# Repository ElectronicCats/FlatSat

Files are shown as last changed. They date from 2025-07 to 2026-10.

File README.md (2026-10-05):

# Flatsat 

<p align="center">
    <a href="https://github.com/ElectronicCats/FlatSat/wiki">
        
    </a>
</p>

<p align=center>
    <a href="https://electroniccats.com/store/flatsat1/">
        
    </a>
    <a href="https://github.com/ElectronicCats/FlatSat/wiki">
        
    </a>
</p>

Flatsat is a hardware based training platform designed to be vulnerable on purpose. It’s built for hackers, engineers, and space enthusiasts who want to dive deep into space-grade systems, learn cybersecurity concepts, and prototype their own payloads.

Flatsat is designed to help you learn and prototype radio systems safely and legally, all while gaining real-world skills in RF communication, signal analysis, and protocol fuzzing.

## What You Can Do With Flatsat
- **Hands-on Learning:** Use Flatsat as the hardware companion to the [**PwnSat**](https://pwnsat.org/) course, with structured lessons on binary exploitation, secure communication, reverse engineering, and space protocols.
- **Hack Real Vulnerabilities:**  Explore and exploit firmware designed to simulate real-world satellite systems and vulnerabilities. It’s a safe playground for learning and discovery.
- **Join the Mission CTF:**  Participate in space-themed capture-the-flag challenges that simulate real satellite operation scenarios.
- **Prototype Your Payloads:**  Use the onboard components to develop and test your own payload logic, radio communication, or telemetry systems before launching bigger projects.

> [!IMPORTANT]
> **This project was created for educational purposes, to teach and learn aerospace cybersecurity. Neither PWNSAT nor Electronic Cats are responsible for how the knowledge, code, or tools hosted in the official repository are used. Use only against hardware, firmware, or signal sources you own or are explicitly authorized to test.**
> 
> Flatsat uses ISM (Industrial, Scientific, and Medical) band frequencies for all RF communication,  typically 433 MHz or 915 MHz, depending on your region. These frequencies are internationally reserved for unlicensed, experimental, and educational use.
>
> This ensures that Flatsat does not interfere with any production space systems, licensed satellites, or critical ground infrastructure.

## Hardware Infrastructure

The infrastructure is designed for **FlatSat** testing, where hardware components are laid out for accessibility and auditing.

| **Component** | **Description** | **Interface** |
| --- | --- | --- |
| **MCU** | Raspberry Pi RP2040 | Dual Core ARM Cortex-M0+ |
| **Radio 0** | SX1262 LoRa (Uplink) | SPI0 / NSS Pin 17 |
| **Radio 1** | SX1262 LoRa (Downlink) | SPI0 / NSS Pin 5 |
| **IMU** | LIS2DH12 Accelerometer | I2C (SDA 20, SCL 21) |
| **ENV** | BME280 Environment Sensor | I2C (SDA 20, SCL 21) |
| **Status** | WS2812B NeoPixel | GPIO 15 |

##  FlatSat Firmware

The firmware splits tasks across two cores, the system ensures that high-speed data links do not interfere with time-critical radio operations.

The firmware is located in a different repository: https://github.com/ElectronicCats/flatsat-ground-station

The core of the communication system is the [**CCSDS Space Packet Protocol**](https://ccsds.org/Pubs/133x0b2e2.pdf). This allows the spacecraft to route data using **Application Process Identifiers (APIDs)**, enabling modular subsystem addressing.

Modern satellites are no longer isolated systems; they are software-defined assets. The vulnerabilities identified in this firmware mirror historical "anomalies" and documented attacks on orbiting infrastructure.

Since the firmware lacks a Cryptographic Authentication layer, the system is vulnerable to **Command Spoofing**.

An attacker uses a Software Defined Radio (SDR) to capture a legitimate "Telemetry" packet to identify the `SPACECRAFT_ID` and the current `Sequence Count`.
  
This happened in the real world. In 1998, the **ROSAT** (Röntgen Satellite) was allegedly compromised via a ground station breach, where attackers sent commands to point the solar panels directly at the sun, eventually frying the batteries. While that was a network breach, the lack of authentication on the RF link makes this firmware susceptible to the same outcome.

## Technical Documentation and Guides (Wiki)

All deep technical documentation, source analysis, and setup guides have been centralized. If you want to start debugging, or exploiting the platform, please visit the [FlatSat Wiki](https://github.com/ElectronicCats/FlatSat/wiki). The information from the Pwnsat repository has been included in our wiki.

## How to contribute 

[pwnsat.org](https://pwnsat.org/) and [flatsat.org](https://flatsat.org/)
Contributions are welcome!

Please read the document [**Contribution manual**](https://github.com/ElectronicCats/electroniccats-cla/blob/main/electroniccats-contribution-manual.md) which will show you how to contribute your changes to the project.

✨ Thanks to all our [Contributors](https://github.com/ElectronicCats/Flatsat/graphs/contributors)! ✨

See [**_Electronic Cats CLA_**](https://github.com/ElectronicCats/electroniccats-cla/blob/main/electroniccats-cla.md) for more information.

See the [**Community code of conduct**](https://github.com/ElectronicCats/electroniccats-cla/blob/main/electroniccats-community-code-of-conduct.md) for a vision of the community we want to build and what we expect from it.

## License

Electronic Cats invests time and resources providing this open source design, please support Electronic Cats and open-source hardware by purchasing products from Electronic Cats!

Designed by Electronic Cats and PWNSAT.

Hardware released under an CERN Open Hardware Licence v1.2. See the LICENSE_HARDWARE file for more information.

Electronic Cats and PWNSAT is a registered trademark, please do not use if you sell these PCBs.

## Special Thanks
A special thanks to **Alex Lynd**. His support made it possible to kick off the first version of the project, and his contribution remains a fundamental part of PwnSat. His work will always be embedded in what this project has become.

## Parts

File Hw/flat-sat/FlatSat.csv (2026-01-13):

Reference | Value | Footprint | Qty | LCSC# | Mouser# | manf# | DNP
BOOT1,Button1,Button2,RESET1 | SW | FlatSat:TS1088R02026 | 4 | C455281
C1,C5,C7,C8,C13,C14,C18,C19,C24,C25,C27,C28,C32,C33,C34,C35,C36,C37,C38 | 0.1uF | Capacitor_SMD:C_0402_1005Metric | 19 | C56392
C2,C15 | 100pF | Capacitor_SMD:C_0402_1005Metric | 2 | C541374
C3,C4,C16,C17 | 3.3pF | Capacitor_SMD:C_0402_1005Metric | 4 | C1565
C6,C26,C31 | 1uF | Capacitor_SMD:C_0402_1005Metric | 3 | C52923
C9,C20 | 47pF | Capacitor_SMD:C_0402_1005Metric | 2 | C437519
C10,C12,C21,C23 | 1nF | Capacitor_SMD:C_0402_1005Metric | 4 | C335530
C11,C22 | 470nF | Capacitor_SMD:C_0402_1005Metric | 2 | C47339
C29,C30 | 27pF | Capacitor_SMD:C_0402_1005Metric | 2 | C424826 | 81-GJM1555C1H270FB1D
D2 | SK6812MINI | Library:SK6812MINI-HS | 1 | C2922787
F1 | 0.75A | Fuse:Fuse_0603_1608Metric_Pad1.05x0.95mm_HandSolder | 1 | C182438 | 594-MFU0805FF00500P1
J1,J2 | Antenna | FlatSat:SMA_EDGE | 2 | C530661
J3 | periphs | Connector_PinHeader_2.54mm:PinHeader_1x06_P2.54mm_Vertical | 1
J4 | SWD | Connector_PinHeader_2.54mm:PinHeader_1x04_P2.54mm_Vertical | 1 |  |  |  | DNP
JP1,JP2 | Jumper | Jumper:SolderJumper-3_P1.3mm_Bridged12_RoundedPad1.0x1.5mm_NumberLabels | 2 |  |  |  | DNP
L1,L4 | 9.1nH | Inductor_SMD:L_0603_1608Metric | 2 | C395094
L2,L5 | 47nH | Inductor_SMD:L_0603_1608Metric | 2 | C578001
L3,L6 | 15uH | Inductor_SMD:L_0603_1608Metric | 2 | C57838
P1 | USB_C_Plug_USB2.0 | FlatSat:C393939 | 1 | C709357
R1,R2 | 5k1 | Resistor_SMD:R_0402_1005Metric | 2 | C25905
R3,R4,R6,R7 | 100R | Resistor_SMD:R_0402_1005Metric | 4 | C25076
R5 | 10k | Resistor_SMD:R_0402_1005Metric | 1 | C25531 | 594-MCS04020D1002BE0
R8,R10 | 27 | Resistor_SMD:R_0402_1005Metric | 2 | C25100 | 755-ESR01MZPF27R0
R9,R15 | 4.7k | Resistor_SMD:R_0402_1005Metric | 2 | C25900 | 594-MCS04020D1002BE0
R13 | 1k | Resistor_SMD:R_0402_1005Metric | 1 | C11702 | 594-MCS0402MD1001DE0
R14 | 470 | Resistor_SMD:R_0402_1005Metric | 1 | C25117
U1 | TLV75733PDBVR | Package_TO_SOT_SMD:SOT-23-5 | 1 | C485517
U2,U6 | 0900FM15D0039 | FlatSat:0900FM15D0039E | 2 |  | 609-0900FM15D0039E | 0900FM15D0039E
U3,U7 | PE42421 | Package_TO_SOT_SMD:SOT-363_SC-70-6 | 2 | C470893 | 81-PE42421SCAA-Z | PE42421SCAA-Z
U4,U8 | SX1262IMLTRT | Package_DFN_QFN:QFN-24-1EP_4x4mm_P0.5mm_EP2.65x2.65mm | 2 | C191341 | 947-SX1262IMLTRT | SX1262IMLTRT
U5 | W25Q16JV | Package_SON:Winbond_USON-8-2EP_3x4mm_P0.8mm_EP0.2x0.8mm | 1 | C571259 | 454-W25Q16JVUUIQTR | W25Q16JVUUIQ TR
U9 | RP2040 | Package_DFN_QFN:QFN-56-1EP_7x7mm_P0.4mm_EP3.2x3.2mm | 1 | C2040 |  | RP2040
U10 | LIS2DH | Package_LGA:LGA-14_2x2mm_P0.35mm_LayoutBorder3x4y | 1 | C155670
U11 | BME280 /BMP280 | Package_LGA:Bosch_LGA-8_2.5x2.5mm_P0.65mm_ClockwisePinNumbering | 1 | C92489
Y1,Y2 | 32Mhz | Crystal:Crystal_SMD_2520-4Pin_2.5x2.0mm | 2 | C255969 |  | Q24FA20H0021700
Y3 | 12MHz | Crystal:Crystal_SMD_3225-4Pin_3.2x2.5mm | 1 | C2848217 |  | XC32M4-12.000-F20NJDT

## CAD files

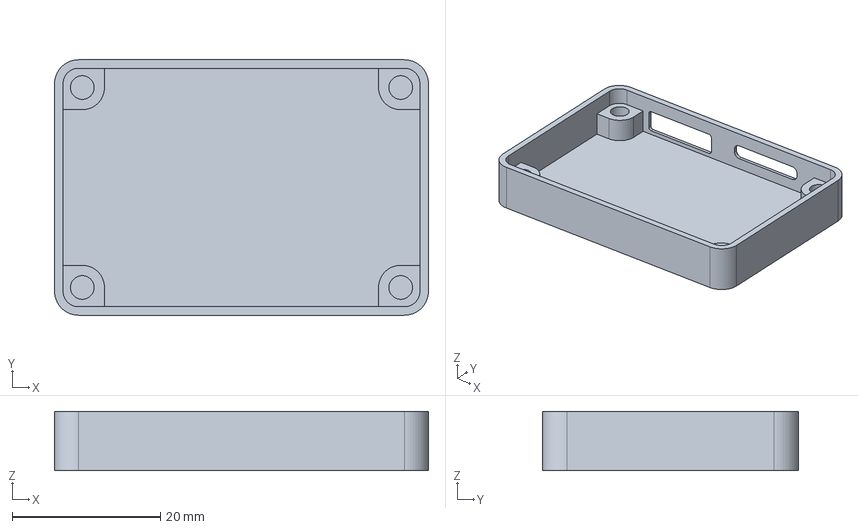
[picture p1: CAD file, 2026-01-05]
Hw/v0.2/v0-FlatSat-Enclosure.FCStd
50.5 x 34.5 x 8.00 mm

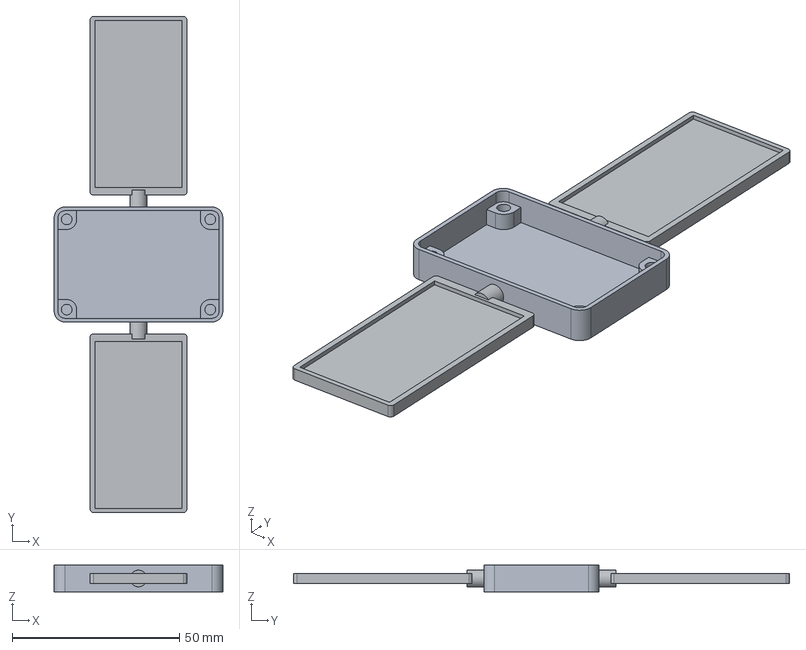
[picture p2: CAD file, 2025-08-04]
Hw/v0.2/v0-FlatSat-Sat-SolarPanel.step
50.5 x 148.5 x 8.00 mm
SolarPanel2
SolarPanel1

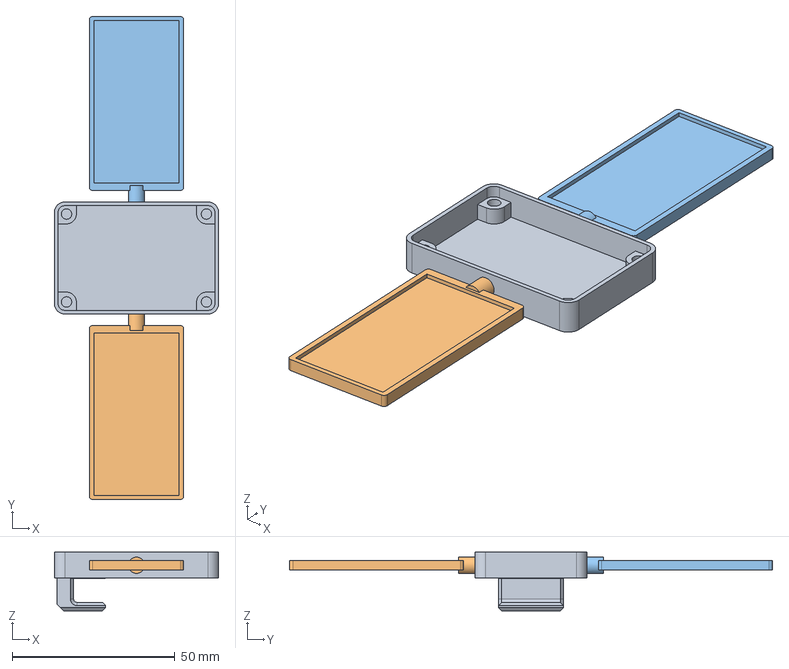
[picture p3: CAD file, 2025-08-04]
Hw/v0.2/v0-FlatSat-Sat_MOunt.FCStd
50.5 x 148.5 x 18.0 mm
SolarPanel2
SolarPanel1

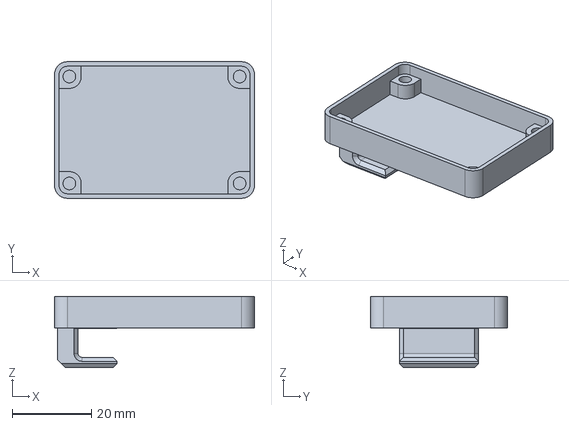
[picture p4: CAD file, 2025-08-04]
Hw/v0.2/v0-FlatSat-Mount.FCStd
50.5 x 34.5 x 18.0 mm

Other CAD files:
Hw/v0.2/v0-FlatSat-Enclosure-Body_STL.stl
Hw/v0.2/v0-FlatSat-Sat.FCStd
Hw/v0.2/v0-FlatSat-Outline.FCStd
Hw/v0.2/v0-FlatSat-Sat-Mount.stl
Hw/v0.2/v0-FlatSat-Sat-SolarPanel.stl

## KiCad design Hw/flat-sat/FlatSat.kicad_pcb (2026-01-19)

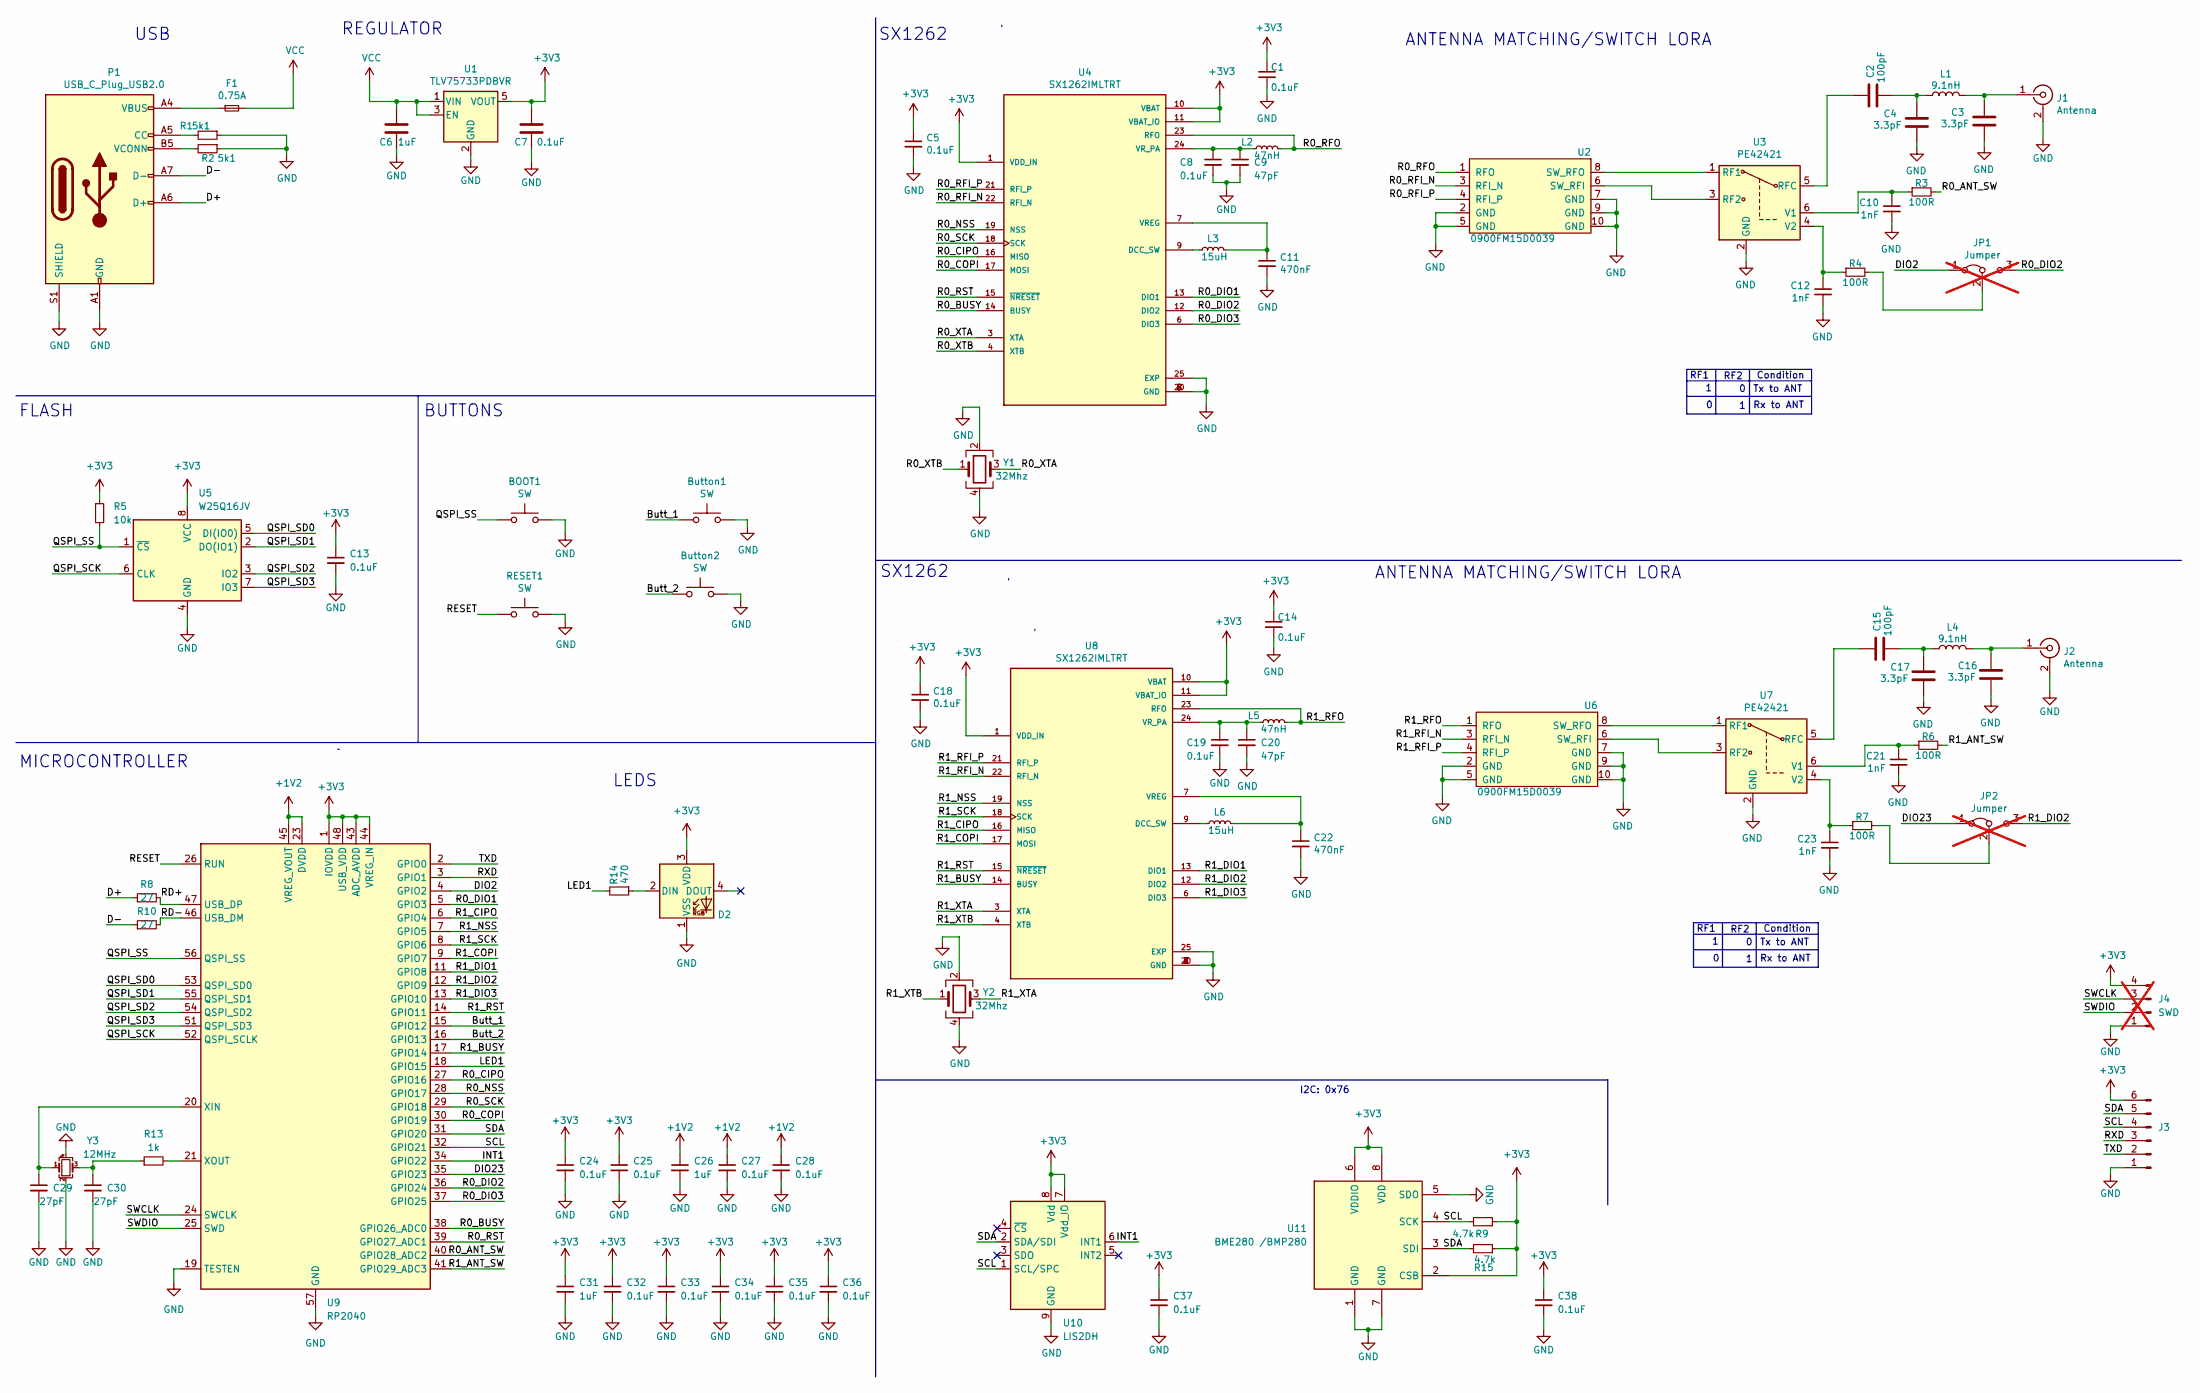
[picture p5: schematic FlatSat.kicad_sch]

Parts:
BOOT1: SW; TS1088R02026; LCSC# C455281
Button1, Button2: SW; TS1088R02026; LCSC# C455281
C1, C5, C7, C8, C13, C14, C18, C19, C24, C25, C27, C28, C32, C33, C34, C35, C36, C37, C38: 0.1uF; C_0402_1005Metric; LCSC# C56392
C2, C15: 100pF; C_0402_1005Metric; LCSC# C541374
C3, C4, C16, C17: 3.3pF; C_0402_1005Metric; LCSC# C1565
C6, C26, C31: 1uF; C_0402_1005Metric; LCSC# C52923
C9, C20: 47pF; C_0402_1005Metric; LCSC# C437519
C10, C12, C21, C23: 1nF; C_0402_1005Metric; LCSC# C335530
C11, C22: 470nF; C_0402_1005Metric; LCSC# C47339
C29, C30: 27pF; C_0402_1005Metric; Mouser# 81-GJM1555C1H270FB1D; LCSC# C424826
D2: SK6812MINI; SK6812MINI-HS; LCSC# C2922787
F1: 0.75A; Fuse_0603_1608Metric_Pad1.05x0.95mm_HandSolder; Mouser# 594-MFU0805FF00500P1
J1, J2: Antenna; SMA_EDGE; LCSC# C530661
J3: periphs; PinHeader_1x06_P2.54mm_Vertical
J4: SWD; PinHeader_1x04_P2.54mm_Vertical; not fitted
JP1, JP2: Jumper; SolderJumper-3_P1.3mm_Bridged12_RoundedPad1.0x1.5mm_NumberL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; not fitted
L1, L4: 9.1nH; L_0603_1608Metric; LCSC# C395094
L2, L5: 47nH; L_0603_1608Metric; LCSC# C578001
L3, L6: 15uH; L_0603_1608Metric; LCSC# C57838
P1: USB_C_Plug_USB2.0; C393939; LCSC# C709357
R1, R2: 5k1; R_0402_1005Metric; LCSC# C25905
R3, R4, R6, R7: 100R; R_0402_1005Metric; LCSC# C25076
R5: 10k; R_0402_1005Metric; Mouser# 594-MCS04020D1002BE0; LCSC# C25531
R8, R10: 27; R_0402_1005Metric; Mouser# 755-ESR01MZPF27R0; LCSC# C25100
R9, R15: 4.7k; R_0402_1005Metric; Mouser# 594-MCS04020D1002BE0; LCSC# C25900
R13: 1k; R_0402_1005Metric; Mouser# 594-MCS0402MD1001DE0; LCSC# C11702
R14: 470; R_0402_1005Metric; LCSC# C25117
RESET1: SW; TS1088R02026; LCSC# C455281
U1: TLV75733PDBVR; SOT-23-5; LCSC# C485517
U2, U6: 0900FM15D0039; 0900FM15D0039E; Mouser# 609-0900FM15D0039E
U3, U7: PE42421; SOT-363_SC-70-6; Mouser# 81-PE42421SCAA-Z; LCSC# C470893
U4, U8: SX1262IMLTRT; QFN-24-1EP_4x4mm_P0.5mm_EP2.65x2.65mm; Mouser# 947-SX1262IMLTRT
U5: W25Q16JV; Winbond_USON-8-2EP_3x4mm_P0.8mm_EP0.2x0.8mm; Mouser# 454-W25Q16JVUUIQTR
U9: RP2040; QFN-56-1EP_7x7mm_P0.4mm_EP3.2x3.2mm; LCSC# C2040
U10: LIS2DH; LGA-14_2x2mm_P0.35mm_LayoutBorder3x4y; LCSC# C155670
U11: BME280 /BMP280; Bosch_LGA-8_2.5x2.5mm_P0.65mm_ClockwisePinNumbering; LCSC# C92489
Y1, Y2: 32Mhz; Crystal_SMD_2520-4Pin_2.5x2.0mm; LCSC# C255969
Y3: 12MHz; Crystal_SMD_3225-4Pin_3.2x2.5mm; LCSC# C2848217

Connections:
+1V2: C26.1, C27.1, C28.1, U9.23 (DVDD), U9.45 (VREG_VOUT), U9.50 (DVDD)
+3V3: C1.1, C5.1, C7.2, C13.1, C14.1, C18.1, C24.1, C25.1, C31.1, C32.1, C33.1, C34.1, C35.1, C36.1, C37.1, C38.1, D2.3 (VDD), J3.6, J4.4, R5.1, R9.1, R15.1, U1.5 (VOUT), U4.1 (VDD_IN), U4.10 (VBAT), U4.11 (VBAT_IO), U5.8 (VCC), U8.1 (VDD_IN), U8.10 (VBAT), U8.11 (VBAT_IO), U9.1 (IOVDD), U9.10 (IOVDD), U9.22 (IOVDD), U9.33 (IOVDD), U9.42 (IOVDD), U9.43 (ADC_AVDD), U9.44 (VREG_IN), U9.48 (USB_VDD), U9.49 (IOVDD), U10.7 (Vdd_IO), U10.8 (Vdd), U11.2 (CSB), U11.6 (VDDIO), U11.8 (VDD)
/Butt_1: Button1.1, U9.15 (GPIO12)
/Butt_2: Button2.1, U9.16 (GPIO13)
/D+: P1.A6 (D+), R8.1
/D-: P1.A7 (D-), R10.1
/DIO2: JP1.1 (A), U9.4 (GPIO2)
/DIO23: JP2.1 (A), U9.35 (GPIO23)
/INT1: U9.34 (GPIO22), U10.6 (INT1)
/LED1: R14.2, U9.18 (GPIO15)
/QSPI_SCK: U5.6 (CLK), U9.52 (QSPI_SCLK)
/QSPI_SD0: U5.5 (DI(IO0)), U9.53 (QSPI_SD0)
/QSPI_SD1: U5.2 (DO(IO1)), U9.55 (QSPI_SD1)
/QSPI_SD2: U5.3 (IO2), U9.54 (QSPI_SD2)
/QSPI_SD3: U5.7 (IO3), U9.51 (QSPI_SD3)
/QSPI_SS: BOOT1.1, R5.2, U5.1 (~CS), U9.56 (QSPI_SS)
/R0_ANT_SW: R3.2, U9.40 (GPIO28_ADC2)
/R0_BUSY: U4.14 (BUSY), U9.38 (GPIO26_ADC0)
/R0_CIPO: U4.16 (MISO), U9.27 (GPIO16)
/R0_COPI: U4.17 (MOSI), U9.30 (GPIO19)
/R0_DIO1: U4.13 (DIO1), U9.5 (GPIO3)
/R0_DIO2: JP1.3 (B), U4.12 (DIO2), U9.36 (GPIO24)
/R0_DIO3: U4.6 (DIO3), U9.37 (GPIO25)
/R0_NSS: U4.19 (NSS), U9.28 (GPIO17)
/R0_RFI_N: U2.3 (RFI_N), U4.22 (RFI_N)
/R0_RFI_P: U2.4 (RFI_P), U4.21 (RFI_P)
/R0_RFO: L2.2, U2.1 (RFO), U4.23 (RFO)
/R0_RST: U4.15 (~NRESET), U9.39 (GPIO27_ADC1)
/R0_SCK: U4.18 (SCK), U9.29 (GPIO18)
/R0_XTA: U4.3 (XTA), Y1.3
/R0_XTB: U4.4 (XTB), Y1.1
/R1_ANT_SW: R6.2, U9.41 (GPIO29_ADC3)
/R1_BUSY: U8.14 (BUSY), U9.17 (GPIO14)
/R1_CIPO: U8.16 (MISO), U9.6 (GPIO4)
/R1_COPI: U8.17 (MOSI), U9.9 (GPIO7)
/R1_DIO1: U8.13 (DIO1), U9.11 (GPIO8)
/R1_DIO2: JP2.3 (B), U8.12 (DIO2), U9.12 (GPIO9)
/R1_DIO3: U8.6 (DIO3), U9.13 (GPIO10)
/R1_NSS: U8.19 (NSS), U9.7 (GPIO5)
/R1_RFI_N: U6.3 (RFI_N), U8.22 (RFI_N)
/R1_RFI_P: U6.4 (RFI_P), U8.21 (RFI_P)
/R1_RFO: L5.2, U6.1 (RFO), U8.23 (RFO)
/R1_RST: U8.15 (~NRESET), U9.14 (GPIO11)
/R1_SCK: U8.18 (SCK), U9.8 (GPIO6)
/R1_XTA: U8.3 (XTA), Y2.3
/R1_XTB: U8.4 (XTB), Y2.1
/RD+: R8.2, U9.47 (USB_DP)
/RD-: R10.2, U9.46 (USB_DM)
/RESET: RESET1.1, U9.26 (RUN)
/RXD: J3.3, U9.3 (GPIO1)
/SCL: J3.4, R9.2, U9.32 (GPIO21), U10.1 (SCL/SPC), U11.4 (SCK)
/SDA: J3.5, R15.2, U9.31 (GPIO20), U10.2 (SDA/SDI), U11.3 (SDI)
/SWCLK: J4.3, U9.24 (SWCLK)
/SWDIO: J4.2, U9.25 (SWD)
/TXD: J3.2, U9.2 (GPIO0)
GND: BOOT1.2, Button1.2, Button2.2, C1.2, C3.2, C4.2, C5.2, C6.1, C7.1, C8.2, C9.2, C10.2, C11.2, C12.2, C13.2, C14.2, C16.2, C17.2, C18.2, C19.2, C20.2, C21.2, C22.2, C23.2, C24.2, C25.2, C26.2, C27.2, C28.2, C29.2, C30.2, C31.2, C32.2, C33.2, C34.2, C35.2, C36.2, C37.2, C38.2, D2.1 (VSS), J1.2 (Ext), J2.2 (Ext), J3.1, J4.1, P1.A1 (GND), P1.A12 (GND), P1.B1 (GND), P1.B12 (GND), P1.S1 (SHIELD), R1.1, R2.1, RESET1.2, U1.2 (GND), U2.2 (GND), U2.5 (GND), U2.7 (GND), U2.9 (GND), U2.10 (GND), U3.2 (GND), U4.2 (GND), U4.5 (GND), U4.8 (GND), U4.20 (GND), U4.25 (EXP), U5.4 (GND), U6.2 (GND), U6.5 (GND), U6.7 (GND), U6.9 (GND), U6.10 (GND), U7.2 (GND), U8.2 (GND), U8.5 (GND), U8.8 (GND), U8.20 (GND), U8.25 (EXP), U9.19 (TESTEN), U9.57 (GND), U10.9 (GND), U10.10 (GND), U10.11 (GND), U10.12 (GND), U10.13 (GND), U10.14 (GND), U11.1 (GND), U11.5 (SDO), U11.7 (GND), Y1.2, Y1.4, Y2.2, Y2.4, Y3.2, Y3.4
unnamed: C2.2, C4.1, L1.2
unnamed: C15.2, C17.1, L4.2
unnamed: C30.1, R13.1, Y3.3
unnamed: D2.2 (DIN), R14.1
unnamed: F1.1, P1.A4 (VBUS), P1.A9 (VBUS), P1.B4 (VBUS), P1.B9 (VBUS)
unnamed: C3.1, J1.1 (In), L1.1
unnamed: C16.1, J2.1 (In), L4.1
unnamed: JP1.2 (C), R4.2
unnamed: JP2.2 (C), R7.2
unnamed: P1.A5 (CC), R1.2
unnamed: P1.B5 (VCONN), R2.2
unnamed: U2.6 (SW_RFI), U3.3 (RF2)
unnamed: U2.8 (SW_RFO), U3.1 (RF1)
unnamed: C2.1, U3.5 (RFC)
unnamed: C10.1, R3.1, U3.6 (V1)
unnamed: C12.1, R4.1, U3.4 (V2)
unnamed: L3.1, U4.9 (DCC_SW)
unnamed: C11.1, L3.2, U4.7 (VREG)
unnamed: C8.1, C9.1, L2.1, U4.24 (VR_PA)
unnamed: U6.6 (SW_RFI), U7.3 (RF2)
unnamed: U6.8 (SW_RFO), U7.1 (RF1)
unnamed: C15.1, U7.5 (RFC)
unnamed: C21.1, R6.1, U7.6 (V1)
unnamed: C23.1, R7.1, U7.4 (V2)
unnamed: L6.1, U8.9 (DCC_SW)
unnamed: C22.1, L6.2, U8.7 (VREG)
unnamed: C19.1, C20.1, L5.1, U8.24 (VR_PA)
unnamed: C29.1, U9.20 (XIN), Y3.1
unnamed: R13.2, U9.21 (XOUT)
VCC: C6.2, F1.2, U1.1 (VIN), U1.3 (EN)

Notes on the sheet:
Rx to ANT
I2C: 0x76
Condition
REGULATOR
SX1262
ANTENNA MATCHING/SWITCH LORA
RF1
RF2
FLASH
Tx to ANT
BUTTONS
MICROCONTROLLER
USB
SX1262
LEDS

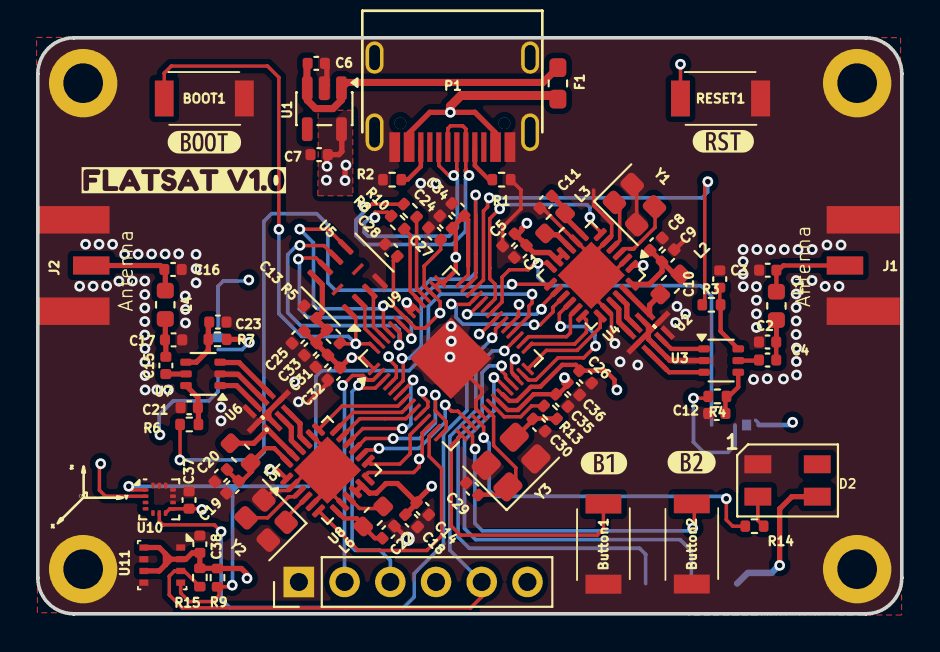
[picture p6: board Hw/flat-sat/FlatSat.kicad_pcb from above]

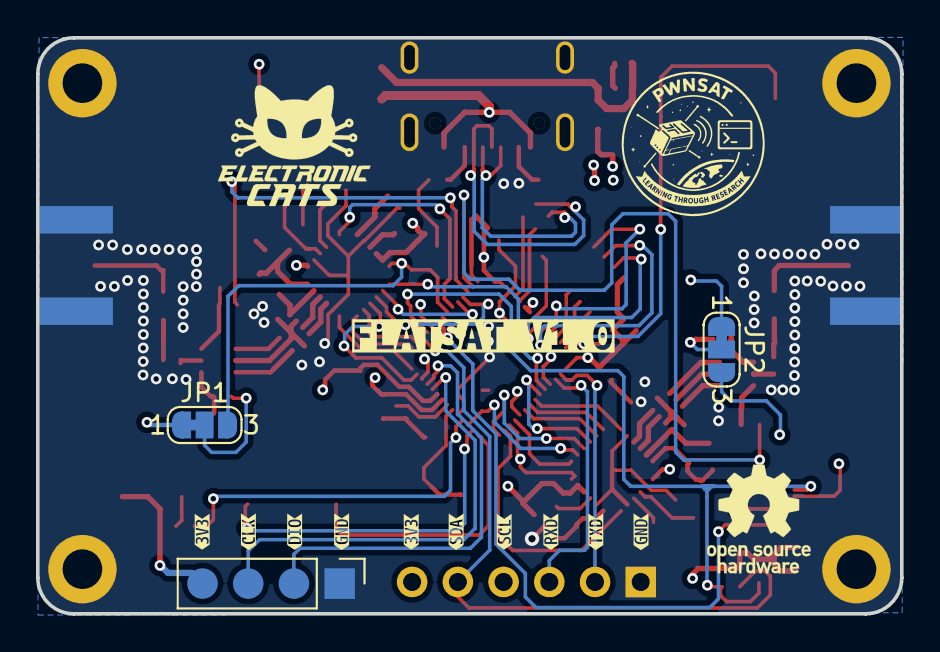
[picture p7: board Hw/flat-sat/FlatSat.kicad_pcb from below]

Board: 4 copper layers, 48.0 x 32.0 mm, 100 parts (14 on the bottom side), 86 nets.

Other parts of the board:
kibuzzard-696512BA, kibuzzard-696512BA#2: G***; kibuzzard-696512BA
kibuzzard-696512FB: G***; kibuzzard-696512FB
kibuzzard-6965130C: G***; kibuzzard-6965130C
kibuzzard-6965136B: G***; kibuzzard-6965136B
kibuzzard-69651236: G***; kibuzzard-69651236
kibuzzard-69651254: G***; kibuzzard-69651254
kibuzzard-69651304: G***; kibuzzard-69651304
kibuzzard-69651319: G***; kibuzzard-69651319
kibuzzard-69651321: G***; kibuzzard-69651321
kibuzzard-69651375: G***; kibuzzard-69651375
kibuzzard-69651380: G***; kibuzzard-69651380
kibuzzard-69652909: G***; kibuzzard-69652909
kibuzzard-69652922: G***; kibuzzard-69652922
kibuzzard-69652959: G***; kibuzzard-69652959
kibuzzard-69653048: G***; kibuzzard-69653048

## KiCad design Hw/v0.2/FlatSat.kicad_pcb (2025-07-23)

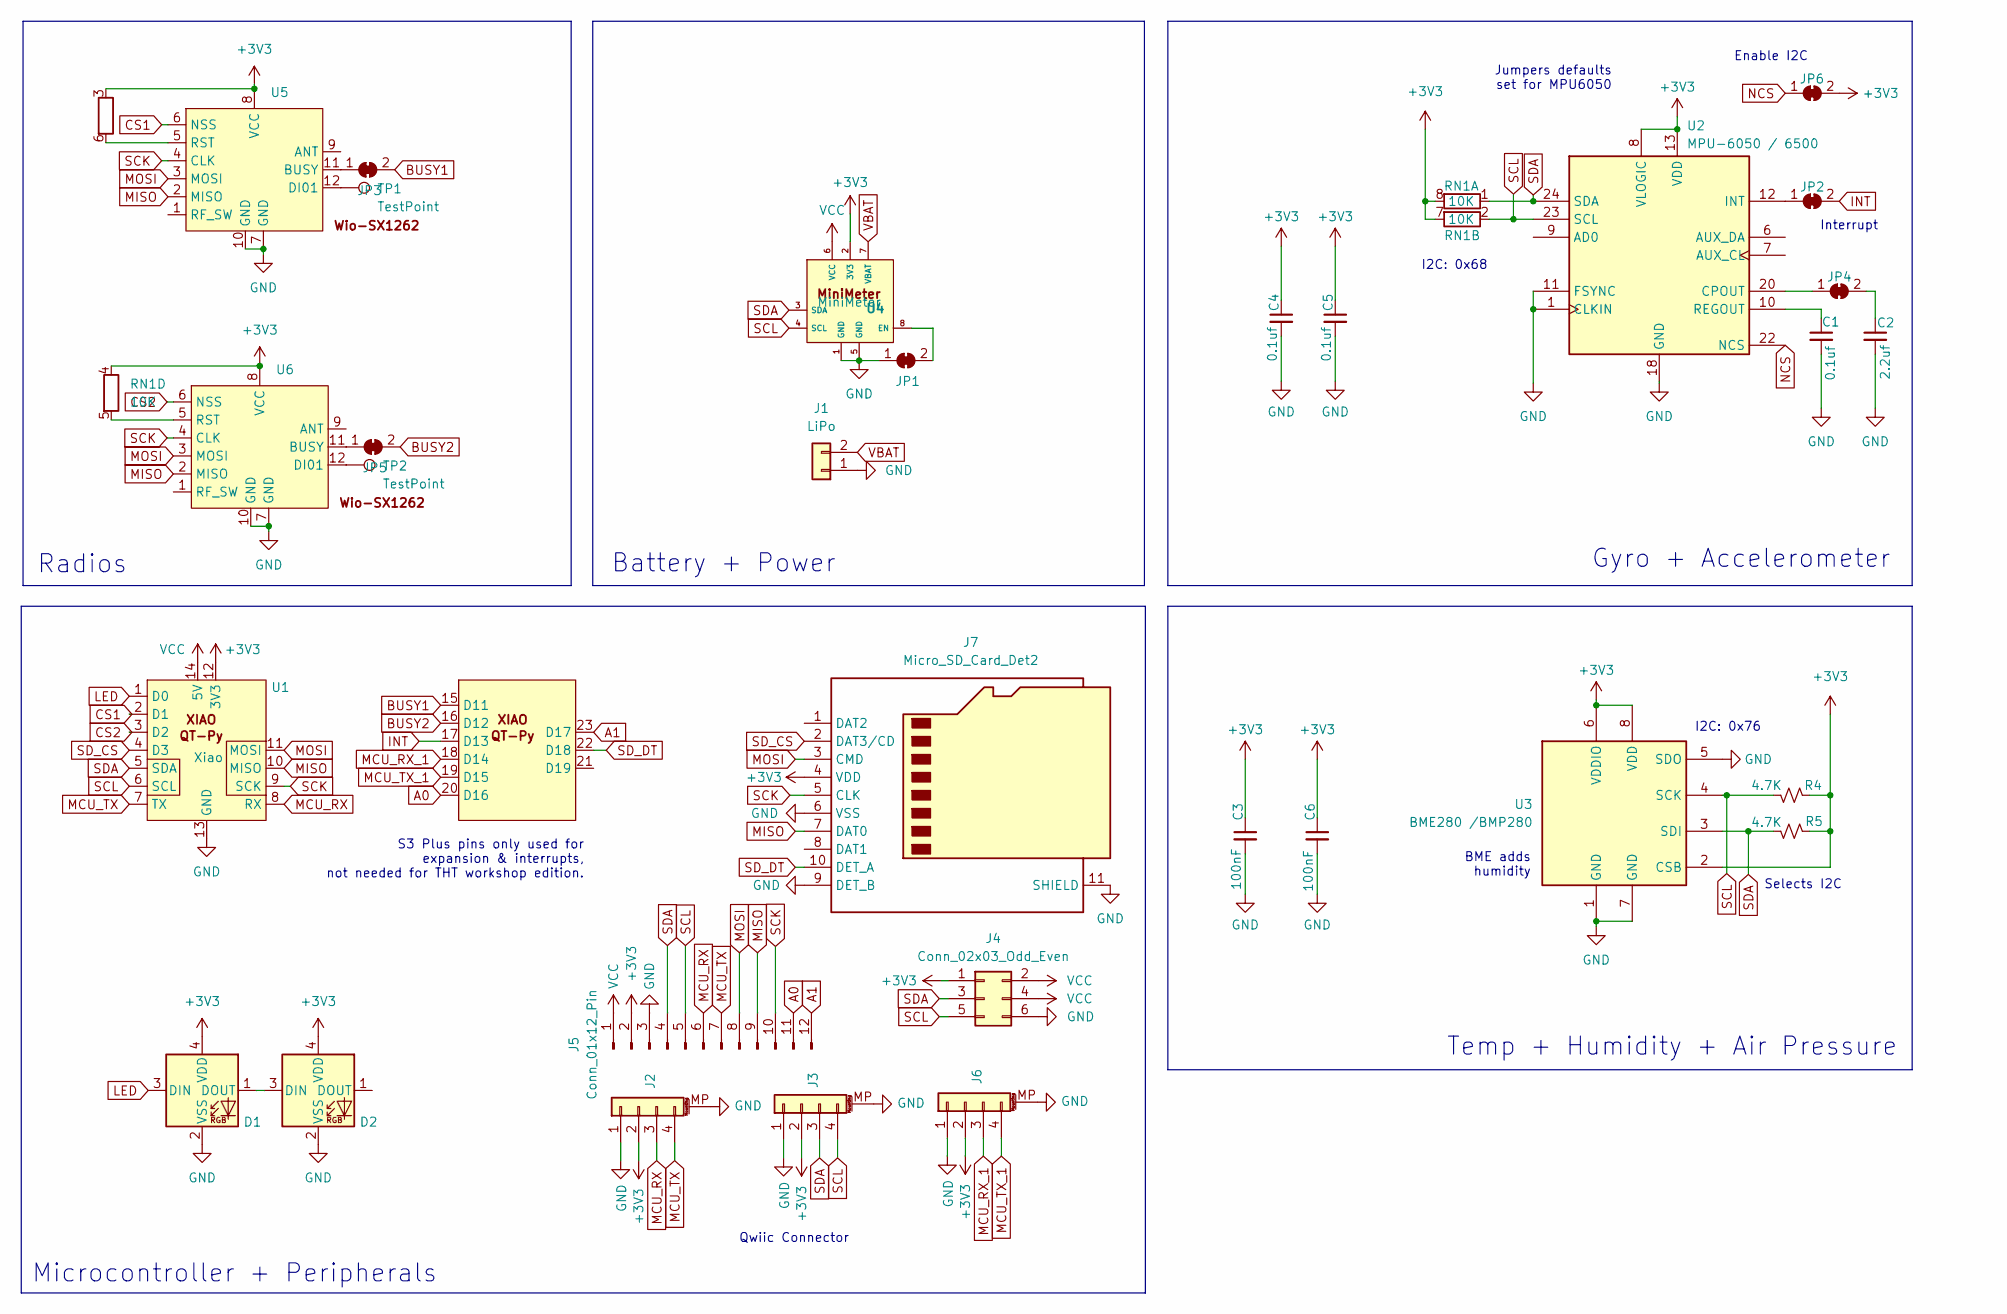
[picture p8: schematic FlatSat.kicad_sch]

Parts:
C1, C4, C5: 0.1uf; C_0603_1608Metric_Pad1.08x0.95mm_HandSolder
C2: 2.2uf; C_0603_1608Metric_Pad1.08x0.95mm_HandSolder
C3, C6: 100nF; C_0603_1608Metric_Pad1.08x0.95mm_HandSolder
D1, D2: SK6812MINI; LED_SK6812MINI_PLCC4_3.5x3.5mm_P1.75mm
J1: LiPo
J2, J3, J6: Conn_01x04_MountingPin
J4: Conn_02x03_Odd_Even
J5: Conn_01x12_Pin
J7: Micro_SD_Card_Det2
JP1, JP2, JP3, JP4, JP5, JP6: SolderJumper_2_Bridged; SolderJumper-2_P1.3mm_Bridged_RoundedPad1.0x1.5mm
R4, R5: 4.7K; R_0603_1608Metric
RN1: 10K; R_Array_Convex_4x0603
TP1: TestPoint; SolderJumper-2_P1.3mm_Open_RoundedPad1.0x1.5mm
TP2: TestPoint
U1: Xiao; XIAO-Generic
U2: MPU-6050 / 6500; InvenSense_QFN-24_4x4mm_P0.5mm
U3: BME280 /BMP280; Bosch_LGA-8_2.5x2.5mm_P0.65mm_ClockwisePinNumbering
U4: MiniMeter
U5, U6: (no value)

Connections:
+3V3: C3.1, C4.1, C5.1, C6.1, D1.4 (VDD), D2.4 (VDD), J2.2, J3.2, J4.1, J5.2, J7.4 (VDD), JP6.2 (B), R4.2, R5.1, RN1.3 (R3.1), RN1.4 (R4.1), RN1.7 (R2.2), RN1.8 (R1.2), U1.12 (3V3), U2.8 (VLOGIC), U2.13 (VDD), U3.2 (CSB), U3.6 (VDDIO), U3.8 (VDD), U4.2 (3V3), U5.8 (VCC), U6.8 (VCC)
A0: J5.11, U1.20 (D16)
A1: J5.12, U1.23 (D17)
BUSY1: JP3.2 (B), U1.15 (D11)
BUSY2: JP5.2 (B), U1.16 (D12)
CS1: U1.2 (D1), U5.6 (NSS)
CS2: U1.3 (D2), U6.6 (NSS)
GND: C1.2, C2.2, C3.2, C4.2, C5.2, C6.2, D1.2 (VSS), D2.2 (VSS), J1.1, J2.1, J2.MP (MountPin), J3.1, J3.MP (MountPin), J4.6, J5.3, J7.6 (VSS), J7.9 (DET_B), J7.11 (SHIELD), JP1.1 (A), U1.13 (GND), U2.1 (CLKIN), U2.11 (FSYNC), U2.18 (GND), U3.1 (GND), U3.5 (SDO), U3.7 (GND), U4.1 (GND), U4.5 (GND), U5.7 (GND), U5.10 (GND), U6.7 (GND), U6.10 (GND); also elsewhere on the board
INT: JP2.2 (B), U1.17 (D13)
LED: D1.3 (DIN), U1.1 (D0)
MCU_RX: J2.3, J5.6, U1.8 (RX)
MCU_RX_1: J6.3, U1.18 (D14)
MCU_TX: J2.4, J5.7, U1.7 (TX)
MCU_TX_1: J6.4, U1.19 (D15)
MISO: J5.9, J7.7 (DAT0), U1.10 (MISO), U5.2 (MISO), U6.2 (MISO)
MOSI: J5.8, J7.3 (CMD), U1.11 (MOSI), U5.3 (MOSI), U6.3 (MOSI)
NCS: JP6.1 (A), U2.22 (NCS)
unnamed: D1.1 (DOUT), D2.3 (DIN)
unnamed: JP1.2 (B), U4.8 (EN)
unnamed: JP2.1 (A), U2.12 (INT)
unnamed: JP3.1 (A), U5.11 (BUSY)
unnamed: JP4.1 (A), U2.20 (CPOUT)
unnamed: C2.1, JP4.2 (B)
unnamed: JP5.1 (A), U6.11 (BUSY)
unnamed: RN1.6 (R3.2), U5.5 (RST)
unnamed: RN1.5 (R4.2), U6.5 (RST)
unnamed: C1.1, U2.10 (REGOUT)
unnamed: TP1.1, U5.12 (DI01)
unnamed: TP2.1, U6.12 (DI01)
SCK: J5.10, J7.5 (CLK), U1.9 (SCK), U5.4 (CLK), U6.4 (CLK)
SCL: J3.4, J4.5, J5.5, R4.1, RN1.2 (R2.1), U1.6 (SCL), U2.23 (SCL), U3.4 (SCK), U4.4 (SCL)
SDA: J3.3, J4.3, J5.4, R5.2, RN1.1 (R1.1), U1.5 (SDA), U2.24 (SDA), U3.3 (SDI), U4.3 (SDA)
SD_CS: J7.2 (DAT3/CD), U1.4 (D3)
SD_DT: J7.10 (DET_A), U1.22 (D18)
VBAT: J1.2, U4.7 (VBAT)
VCC: J4.2, J4.4, J5.1, U1.14 (5V), U4.6 (VCC)

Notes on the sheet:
Radios
Jumpers defaults set for MPU6050
Microcontroller + Peripherals
BME adds humidity
I2C: 0x76
Gyro + Accelerometer
I2C: 0x68
Temp + Humidity + Air Pressure
Selects I2C
Interrupt
Battery + Power
Enable I2C
Qwiic Connector
S3 Plus pins only used for expansion & interrupts, not needed for THT workshop edition.

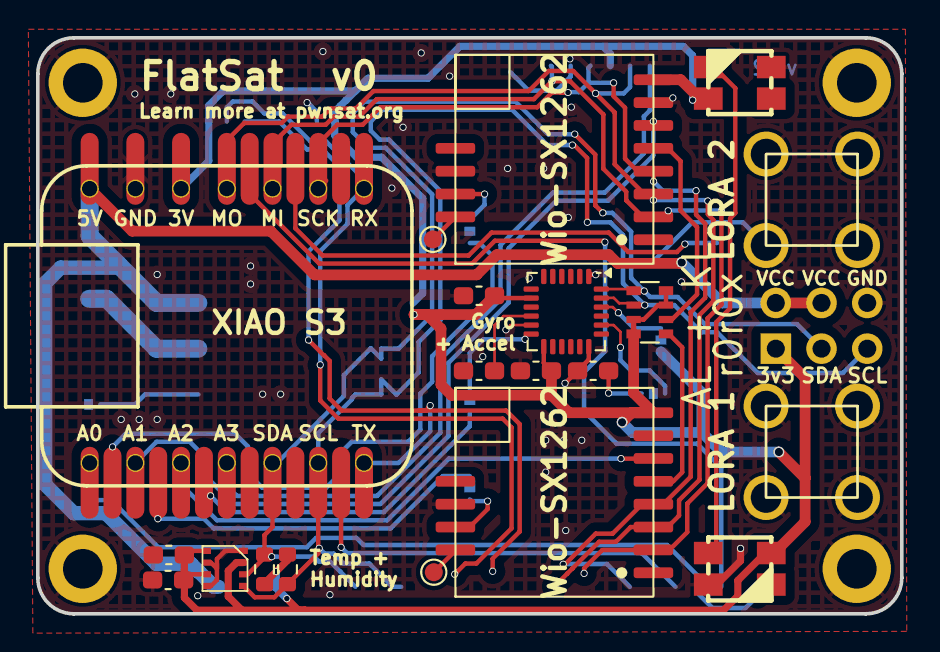
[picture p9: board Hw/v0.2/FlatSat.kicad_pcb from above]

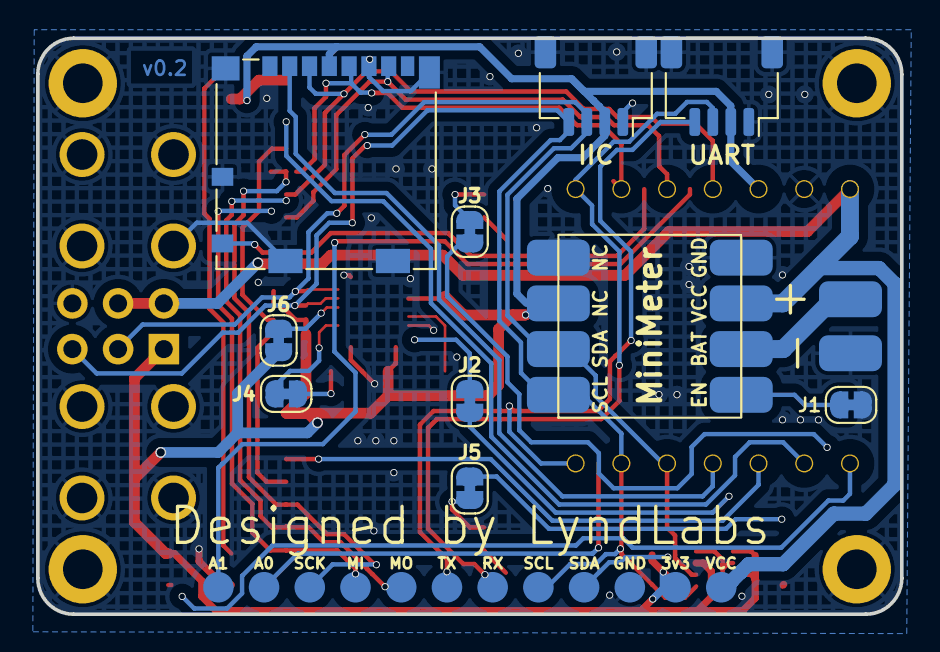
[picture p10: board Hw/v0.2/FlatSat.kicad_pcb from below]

Board: 2 copper layers, 48.0 x 32.0 mm, 33 parts (12 on the bottom side), 34 nets.

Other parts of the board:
AE1, AE2: u.fl to SMA Edge Mount; SMA_Amphenol_901-143_Horizontal

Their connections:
GND: AE1.1, AE2.1; also elsewhere on the board

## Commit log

2025-07-23 update routing for MPU6050 + fix traces + jumpers
    [FlatSat.kicad_pcb, FlatSat.kicad_sch, v0-FlatSat-Outline.FCStd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]
2025-07-23 update v0.2 gerber + pnp file
    [FlatSat.kicad_pcb, v0.1-FlatSat-PNP_250604-R0.csv, v0.2-FlatSat-BOM_250722.csv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]
2025-08-04 feat: Add new cases
    [v0-FlatSat-Enclosure-Body_STL.stl, v0-FlatSat-Mount.FCStd, v0-FlatSat-Sat-Mount.stl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]
2026-01-05 Re-structure repository add new kicad project
    [FlatSat.kicad_pcb, FlatSat.kicad_sch, outline.dxf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]
2026-01-05 Remove previous layout, update gitignore
    [FlatSat.kicad_pcb]
2026-01-05 feat(Hw):Update_sch
    Pending review
    [FlatSat.kicad_sch]
2026-01-06 feat(Hw):Update_Pcb_And
    Pending_some_pins
    [FlatSat.kicad_pcb, FlatSat.kicad_sch]
2026-01-07 feat(Hw):Update_Route
    Pending_Neo
    [FlatSat.kicad_pcb]
2026-01-09 feat(Hw):Update_PCB_Change_Buttons
    Pending_Check_LIS2DH
    [FlatSat.kicad_pcb, FlatSat.kicad_sch]
2026-01-14 Fix(Hw): update RF floorplan
    [FlatSat.kicad_pcb]
2026-01-19 fix ground plane 4 layers
    [FlatSat.kicad_pcb]
